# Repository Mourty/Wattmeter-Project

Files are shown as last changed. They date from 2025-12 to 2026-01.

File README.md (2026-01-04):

# The Wattmeter Project

This project was created for a senior design course as part of my degree path. I wanted to create a wattmeter similar to the "Kill A Watt" meters typically available, but with an important change. I wanted the ability to log the energy consumption data over time. I created a functional prototype well before I even began the class, but decided to iterate on the project and improve it. This is my first project of this scale, and I am sure it isn't perfect. In fact I'm sure it can be improved upon, but it works well enough for me.  
  
### Features
* Single Phase voltage, current, active power, reactive power, apparent power, frequency, and power factor measurement.
* LCD Display for user readable measurements.
* WiFi connectivity with RESTful API
* Configurable via SD card or web interface
* Dedicated Real time clock with automatic NTP syncing (WiFi required)
* Logs data to an SD card for optional independent operation
* Integrated UPS to prevent data loss due to power outage (100ish seconds plenty to automatically save data buffer)
* Monitoring server for remote data collection, storage, and presentation using React and python.

### Hardware
The hardware is a custom designed PCB with mostly through hole components. I chose through hole because it is what I wanted to use, more on this later.
The meter uses the Atmel M90E32 Poly-phase energy monitoring IC to do the heavy lifting of accurate power measurement. The voltage input uses a stepdown transformer and voltage divider to bring the 120VAC input voltage down around a manageable 0.6vrms. The transformer is somewhat unnecessary as a series of resistors could do the same, but this also provides some transient protection and isolation. The current measurement utilizes a current transformer with a carefully sizes burden resistor to bring the voltage down to around 0.6vrms when 20 amps is flowing though the primary of the CT. 
The power supply for the whole board is an off the shelf AC to DC power supply. This provides stable "safe" power without needed to roll my own PSU. This is fed to a super capacitor, then to the LM2621 based boost converted. The super capacitor provided an energy buffer to allow for controlled shutdown of the microcontroller in the event of a power outage. This allows time to write the current buffer of power statistics to the SD card. without this feature the SD card would either need to be written to more often with small amounts of data or the buffer would be lost during a power outage. Depending on the setting this could be multiple minutes or hours of data lost. The size of the super cap was chosen due to part availability at the time; It could easily be a quarter or even an eighth as large and still serve its purpose.
None of the components have been price optimized to a good degree. For example the diodes that are apart of the super capacitor/boost converter are rated for 2 amps, but don't ever see near that amount. These are simply what I had on hand during the design and didn't see a need to order different ones. So If you make this project too, you might want to consider components carefully, you might save some money.

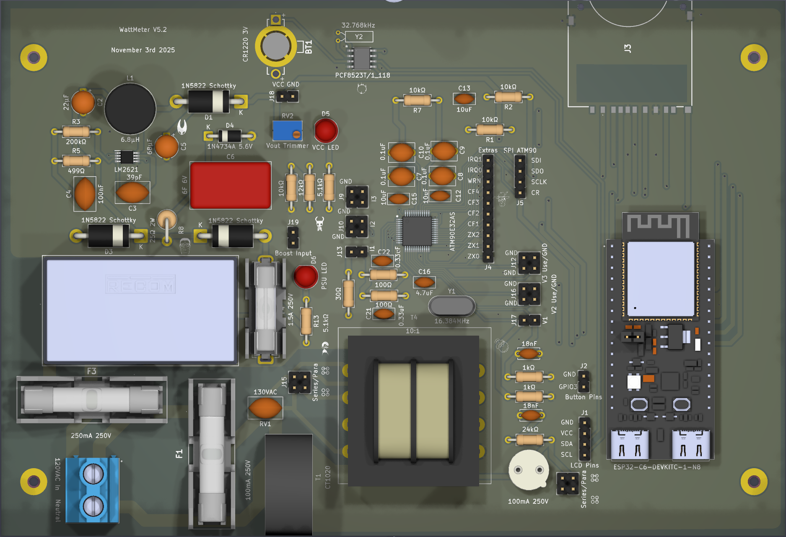
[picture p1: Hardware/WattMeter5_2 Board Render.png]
Wattmeter 5.2 Board Render.


I figured I could improve upon the wattmeter with the wattmeterJR. This version has fewer features, but is smaller and uses SMD components. It lacks an LCD display or the whole integrated UPS part. It is mainly to measure the same power statistics, but really requires the remote server to log the data. it is much less user friendly to build and to debug, but is cheaper and smaller. You can find this version at https://github.com/Mourty/WattmeterJR

### Firmware
I wrote the firmware with assistance from Claude.ai. I'm not the sort to go around proclaiming to be a coder, so you will find issues here. I used the Arduino IDE to develop, compile, and upload the code to the ESP32. The code is semi-organized into different files and imported where needed. The meter itself can be configured using the SD card. You will need to write the settings.ini to the SD card. In the settings you will find a place to configure your WiFi credentials as well as other settings. Many of these will seem cryptic, but most of them won't need to be modified at all. Most are actually configuration registers for the ATM90E32. You can find more on what the do in the IC's datasheet.  
  
### Service
The service is a web server that uses React for the front end and python for the backend. I again used Claude.ai to write much of the code here. The service is containerized using docker, so you should be able to get it up and running fairly easily. I used a Raspberry PI 3+, but in theory any linux computer can run this server. You will need to install docker to compose the containers and to run them. Docker *should* take care of installing other things for the containers like python and such.

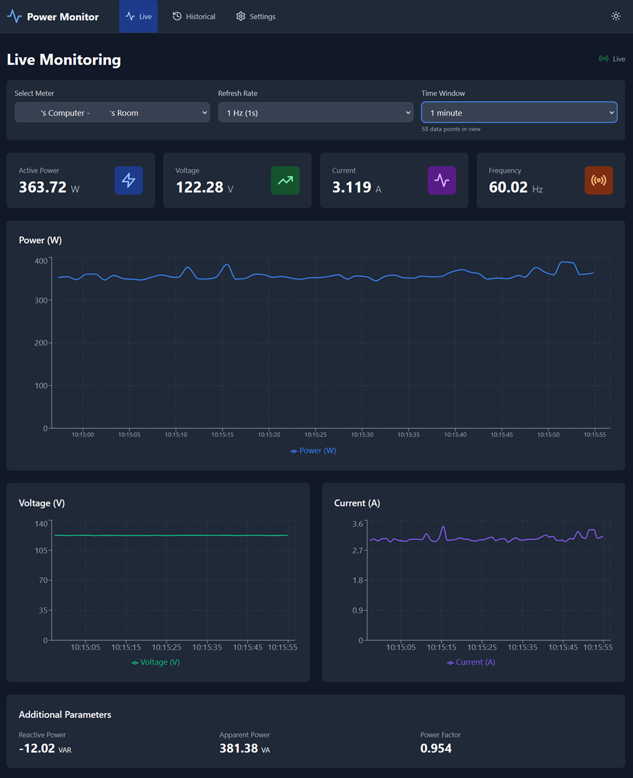
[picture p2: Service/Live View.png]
Live View.


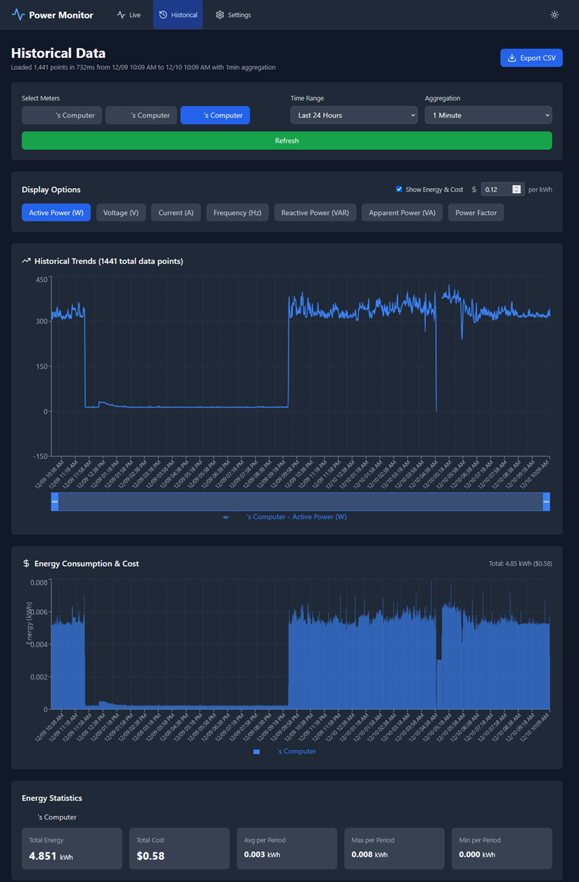
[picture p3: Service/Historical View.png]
Historical View.


I don't plan to maintain this or improve further at this time. If someone wants to improve this feel free, it won't hurt my feelings if you fork this project and do cool things with it, just give me credit for what you use. I have no idea what license this project should have given it uses a few external libraries, so before you go attempting to monetize this project you might need to check on that.

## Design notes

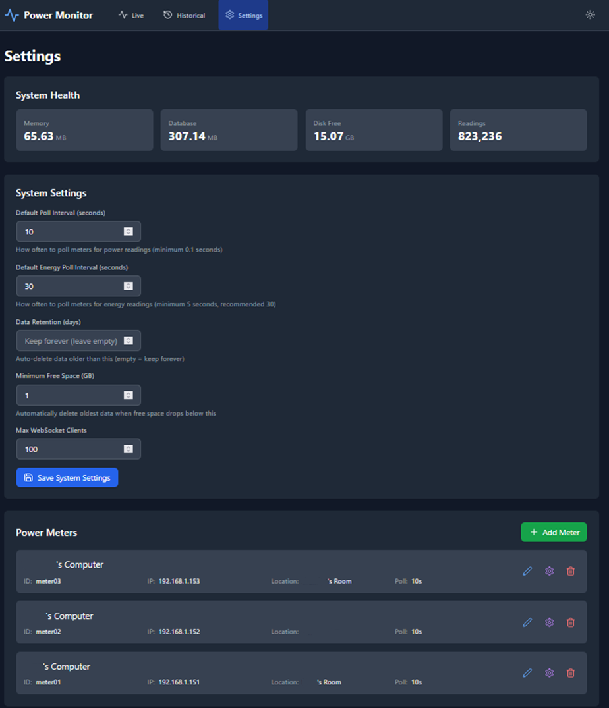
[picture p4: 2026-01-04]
Service/Settings View.png

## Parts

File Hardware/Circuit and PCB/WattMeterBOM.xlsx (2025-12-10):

Reference | Qty | Value | Mouser# | Digikey# | Amazon Link | Price/unit | Line Price
BT1 | 1 | CR1220 | 737-BH-127A-1 |  |  | 0.3 | 0.3
C12,C13,C15 | 3 | 10uF | 810-FG18X5R1E106MR00 |  |  | 0.278 | 0.834
C16 | 1 | 4.7uF | 810-FG28X5R1E475KRT6 |  |  | 0.22 | 0.22
C2 | 1 | 22μF | 581-TAP226K035CCS |  |  | 1.05 | 1.05
C21,C22 | 2 | 0.33uF | 810-FG18X7R1H334KRT6 |  |  | 0.115 | 0.23
C23,C24 | 2 | 18nF | 594-K183K10X7RF53H5 |  |  | 0.121 | 0.242
C3 | 1 | 39pF | 80-C317C390J2G |  |  | 0.12 | 0.12
C4 | 1 | 100nF | 594-K104K15X7RF53L2 |  |  | 0.106 | 0.106
C5 | 1 | 68μF | 581-TAP686K025CCS |  |  | 2.18 | 2.18
C6 | 1 | 6F 6V | 815-ADCMS06R0SA605RB |  |  | 5.51 | 5.51
C7,C8,C9,C10 | 4 | 0.1uF | 594-K104K15X7RF5WH5 |  |  | 0.089 | 0.356
D1,D2,D3 | 3 | 1N5822 Schottky | 511-1N5822 |  |  | 0.28 | 0.84
D4 | 1 | 1N4734A 5.6V | 78-1N4734A |  |  | 0.052 | 0.052
D5 | 1 | VCC LED | 859-LTL-4213 |  |  | 0.088 | 0.088
D6 | 1 | PSU LED | 859-LTL-4213 |  |  | 0.088 | 0.088
F1 | 1 | 100mA 250V | 576-0313.100MXP |  |  | 2.29 | 2.29
F2 | 1 | 100mA 250V | 693-0034.7105 |  |  | 0.814 | 0.814
F3 | 1 | 250mA 250V | 576-0313.250HXP |  |  | 1.43 | 1.43
F4 | 1 | 1.5A 250V |  |  | https://www.amazon.com/dp/B07MCHQQ7Z?ref=ppx_yo2ov_dt_b_fed_asin_title&th=1 | 1.67 | 1.67
IC1 | 1 | ATM90E32AS-AU-R | 556-ATM90E32AS-AU-R |  |  | 3.66 | 3.66
IC2 | 1 | LM2621MMX_NOPB | 926-LM2621MMX/NOPB |  |  | 1.77 | 1.77
J1 | 1 | LCD Pins | 910-HDR100IMP40MGVTH |  |  | 0.058 | 0.058
J10 | 1 | I2 Use/GND | 910-HDR100IMP40MGVTH |  |  | 0.058 | 0.058
J11 | 1 | Input | 490-TB005-762-02BE |  |  | 0.66 | 0.66
J12 | 1 | V3 Use/GND | 910-HDR100IMP40MGVTH |  |  | 0.058 | 0.058
J13 | 1 | I1 | 910-HDR100IMP40MGVTH |  |  | 0.029 | 0.029
J14,J15 | 2 | Series/Para | 910-HDR100IMP40MGVTH |  |  | 0.058 | 0.116
J16 | 1 | V2 Use/GND | 910-HDR100IMP40MGVTH |  |  | 0.058 | 0.058
J17 | 1 | V1 | 910-HDR100IMP40MGVTH |  |  | 0.029 | 0.029
J18 | 1 | VCC Pins | 910-HDR100IMP40MGVTH |  |  | 0.029 | 0.029
J19 | 1 | Boost Input | 910-HDR100IMP40MGVTH |  |  | 0.029 | 0.029
J2 | 1 | Button Pins | 910-HDR100IMP40MGVTH |  |  | 0.0145 | 0.0145
J3 | 1 | GSD09002SEU | 523-GSD09002SEU |  |  | 1.4 | 1.4
J4 | 1 | Extras | 910-HDR100IMP40MGVTH |  |  | 0.145 | 0.145
J5 | 1 | SPI ATM90 | 910-HDR100IMP40MGVTH |  |  | 0.058 | 0.058
J9 | 1 | I3 Use/GND | 910-HDR100IMP40MGVTH |  |  | 0.058 | 0.058
L1 | 1 | 6.8μH | 994-RFS1113-682ME |  |  | 1.65 | 1.65
N1 | 1 | Housing | 546-1591XXFBK |  |  | 19.07 | 19.07
P1 | 1 | Nema 5-15-P |  |  | https://www.amazon.com/Leviton-515PR-Straight-Blade-Rubber/dp/B000FKBZ7M | 3.98 | 3.98
P2 | 1 | Nema 5-15-R |  |  | https://www.amazon.com/dp/B0BMV8DSM1?ref=ppx_yo2ov_dt_b_fed_asin_title | 9.99 | 9.99
PS1 | 1 | RAC10E-05SK_277 | 919-RAC10E-05SK/277 |  |  | 9.64 | 9.64
R1,R2,R4,R7 | 4 | 10kΩ | 603-MFR-25FTE52-10K |  |  | 0.028 | 0.112
R10,R11 | 2 | 100Ω | MFR-25FBF52-100R |  |  | 0.029 | 0.058
R12,R13 | 2 | 5.1kΩ | 603-MFR-25FBF52-5K1 |  |  | 0.029 | 0.058
R14,R18 | 2 | 1kΩ | 603-MFR-25FBF52-1K |  |  | 0.026 | 0.052
R19 | 1 | 24kΩ | 603-MFR-25FBF52-24K |  |  | 0.029 | 0.029
R3 | 1 | 200kΩ | 603-MFR-25FBF52-200K |  |  | 0.029 | 0.029
R5 | 1 | 499Ω | 603-MFR-25FBF52-499R |  |  | 0.027 | 0.027
R6 | 1 | 12kΩ | 603-MFR-25FBF52-12K |  |  | 0.029 | 0.029
R8 | 1 | 25Ω 2W | 588-WNC25RFET |  |  | 1.46 | 1.46
R9 | 1 | 30Ω | 603-MFR-25FBF52-30R |  |  | 0.029 | 0.029
RV1 | 1 | 130VAC | 576-V07E130P |  |  | 0.186 | 0.186
RV2 | 1 | Vout Trimmer | 81-PV36W204C01B00 |  |  | 1.21 | 1.21
T1 | 1 | CT1020 |  | 419-CT1020-ND |  | 6.04 | 6.04
T4 | 1 | 10 to 1 | 838-3FD-224 |  |  | 4.5 | 4.5
U1 | 1 | ESP32-C6-DEVKITC-1-N8 | 356-ESP32C6DKC1N8 |  |  | 8.76 | 8.76
U2 | 1 | ~ |  |  | https://www.amazon.com/dp/B0C1G9GBRZ?ref=ppx_yo2ov_dt_b_fed_asin_title&th=1 | 5.66 | 5.66
U3 | 1 | PCF8523T/1_118 |  | 568-5306-1-ND |  | 1.29 | 1.29
Y1 | 1 | 16.384MHz | 815-ABL-16.384-B2 |  |  | 0.32 | 0.32
Y2 | 1 | 32.768kHz | 815-ABL-16.384-B2 |  |  | 0.32 | 0.32
Total |  |  |  |  |  |  | 101.1485

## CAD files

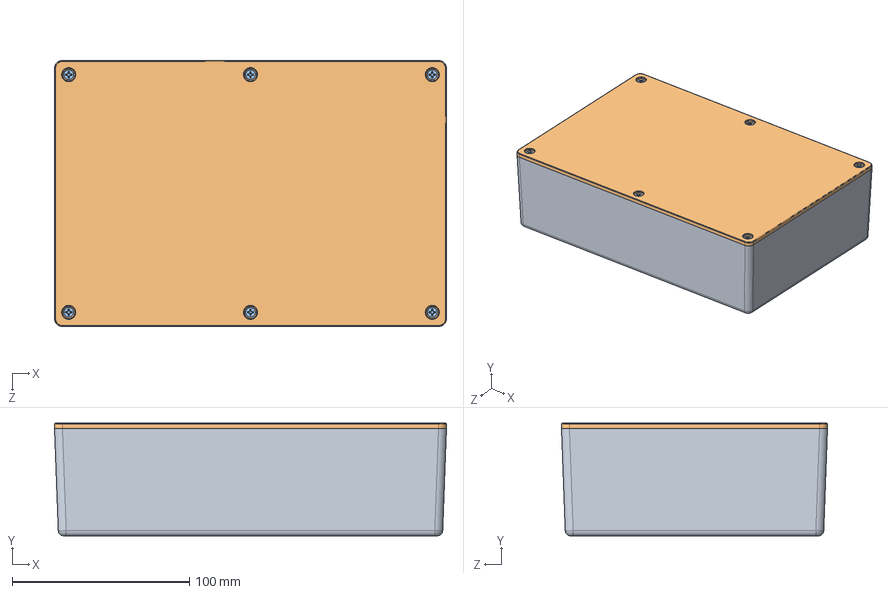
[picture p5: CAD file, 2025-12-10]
Hardware/Solidworks Parts/1591XXFBK.SLDASM
221.0 x 63.5 x 150.0 mm
1591XXF BOX.stp
1591XXF LID.stp
SC500 (screw M3-0.5X 10mm FH).stp x 6
IN100 (insert M3-0.5X5.75mm BRASS).stp x 6

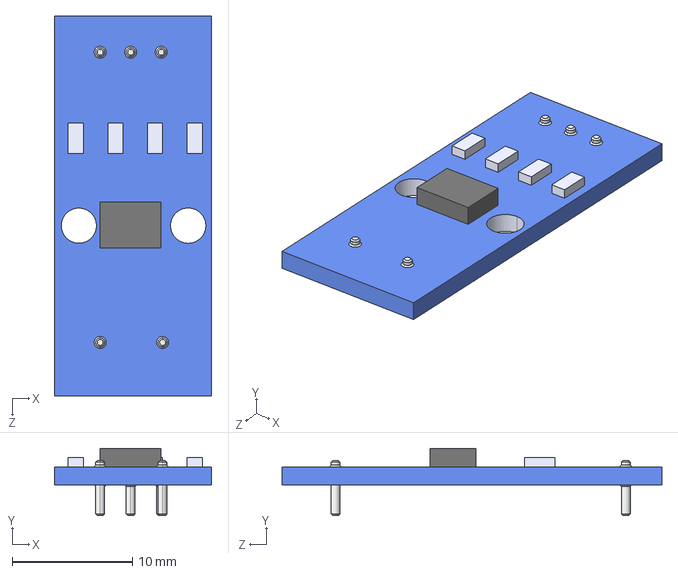
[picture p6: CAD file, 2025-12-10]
Hardware/Solidworks Parts/ACS712 Board.STEP
13.1 x 5.59 x 31.6 mm

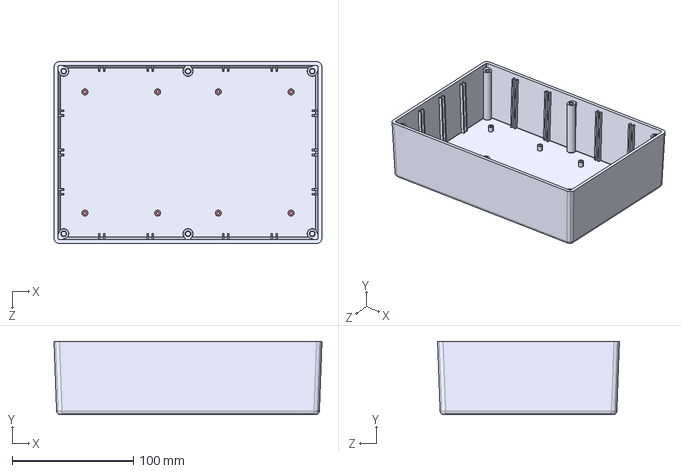
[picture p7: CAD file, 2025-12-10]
Hardware/Solidworks Parts/1591XXFBKBody.STEP
221.0 x 60.5 x 150.0 mm

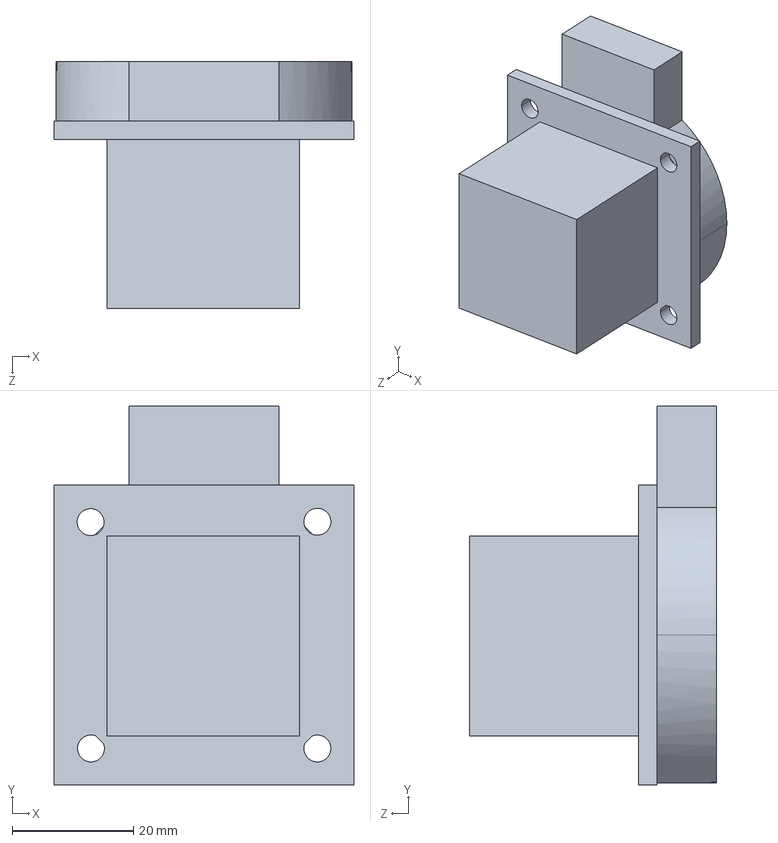
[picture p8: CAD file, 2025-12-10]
Hardware/Solidworks Parts/Nema5-15R Panel Mount.STEP
49.5 x 62.6 x 40.8 mm

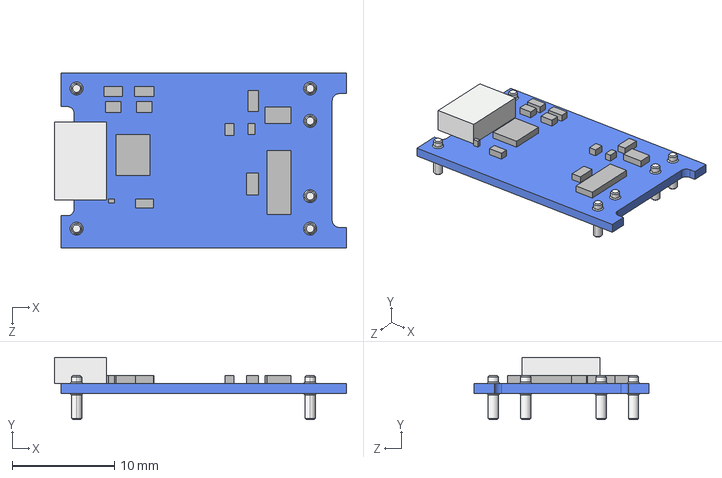
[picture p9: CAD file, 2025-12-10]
Hardware/Solidworks Parts/TP4056 Board.STEP
28.6 x 6.10 x 17.1 mm

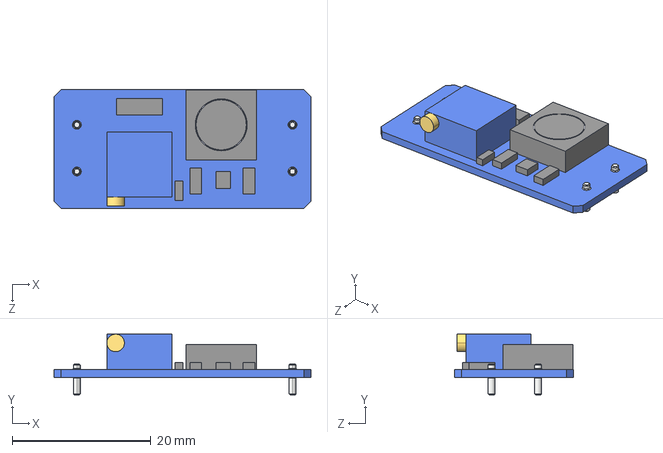
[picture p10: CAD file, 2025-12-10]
Hardware/Solidworks Parts/MT3608 board.STEP
37.1 x 8.76 x 17.1 mm

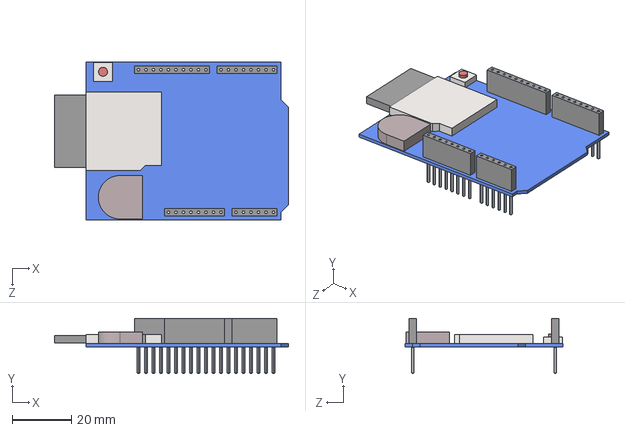
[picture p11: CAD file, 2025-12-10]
Hardware/Solidworks Parts/Datalogging Board.STEP
79.2 x 18.7 x 53.3 mm

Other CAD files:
Hardware/Solidworks Parts/ACS712 Board.SLDPRT
Hardware/Solidworks Parts/Datalogging Board.SLDPRT
Hardware/Solidworks Parts/MT3608 board.SLDPRT
Hardware/Solidworks Parts/Nema5-15R Panel Mount.SLDPRT
Hardware/Solidworks Parts/TP4056 Board.SLDPRT

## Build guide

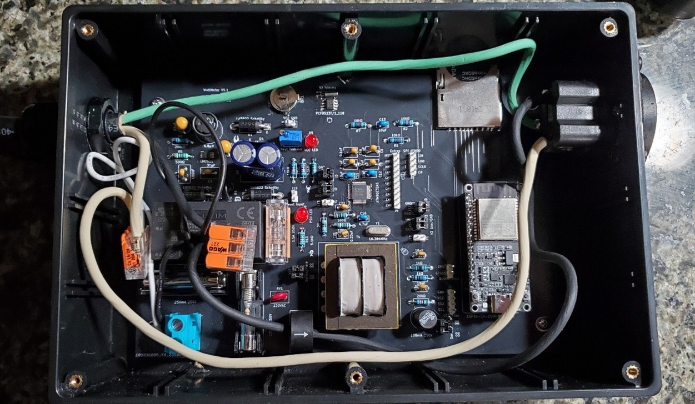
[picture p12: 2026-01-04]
Hardware/Assembled Meter Open Cover.jpg

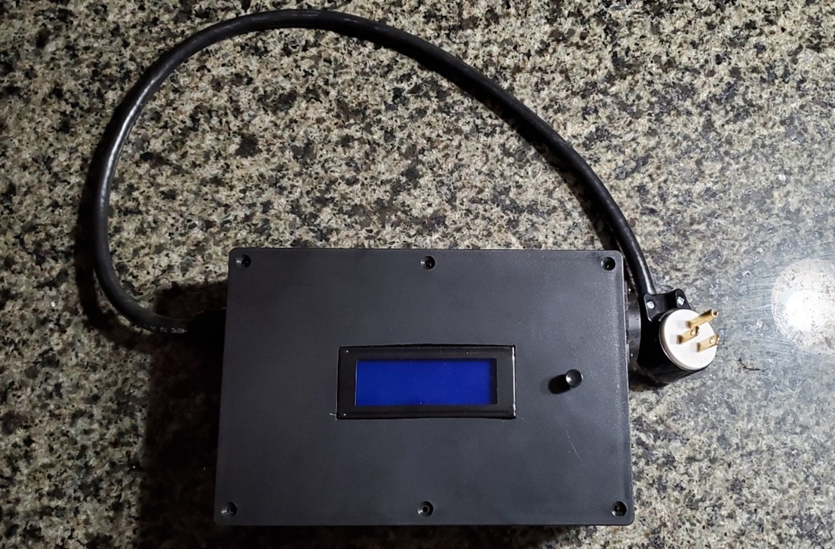
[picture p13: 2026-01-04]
Hardware/Assembled Meter.jpg

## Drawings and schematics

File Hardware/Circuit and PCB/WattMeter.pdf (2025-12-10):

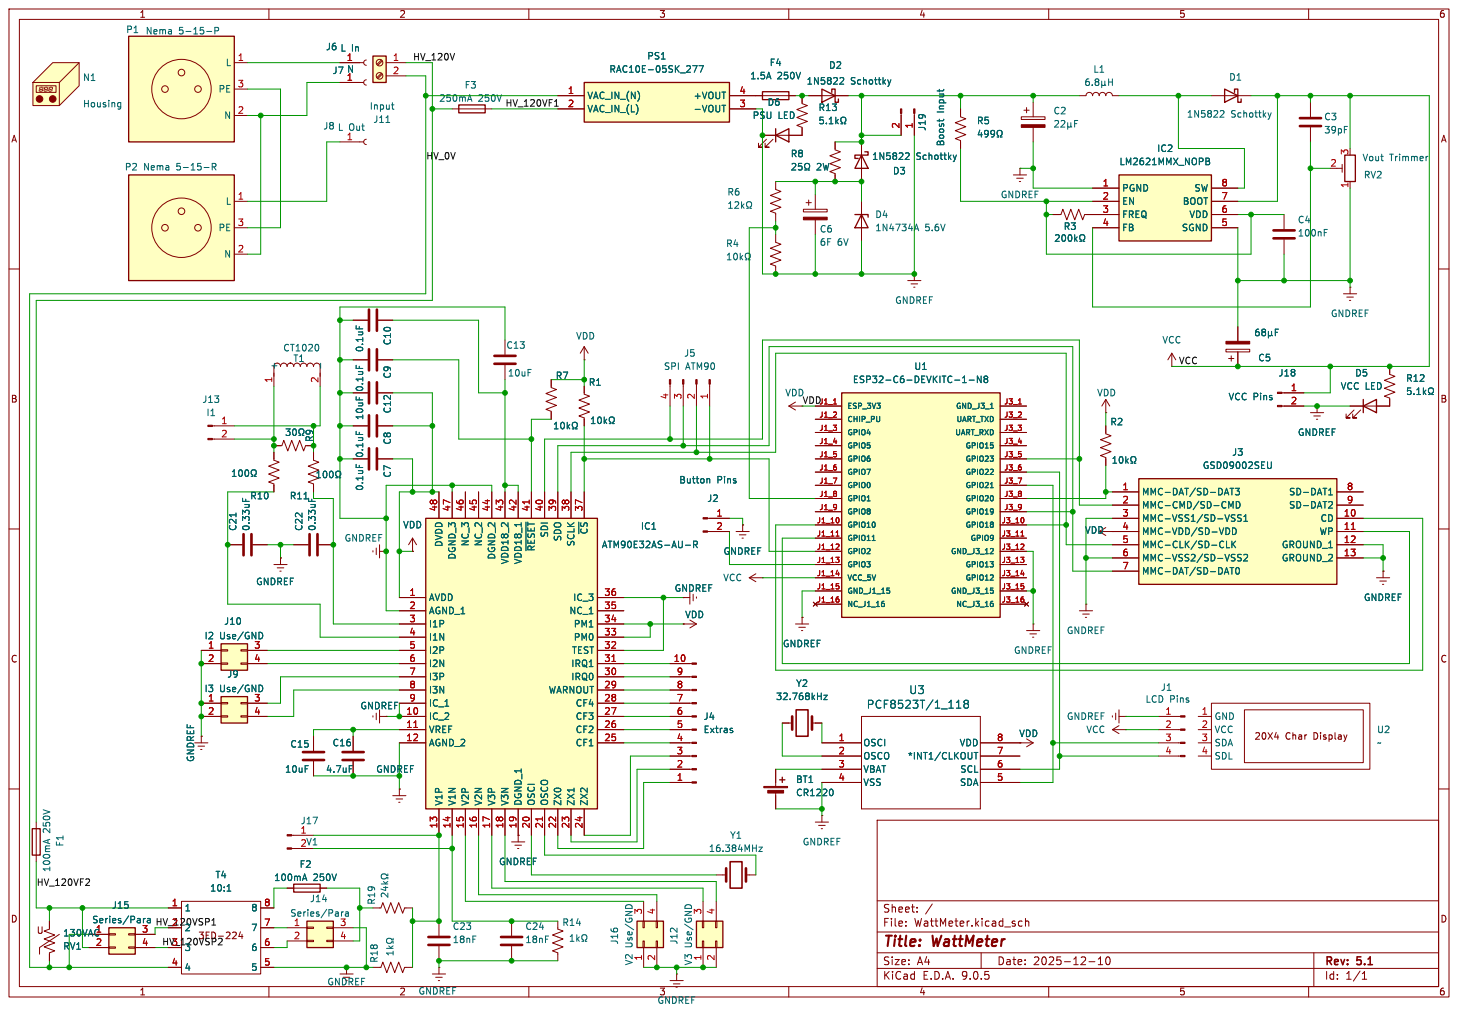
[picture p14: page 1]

4 J16 V2 Use/GND GNDREF GNDREF AVDD 1 AGND_1 2

Id: 1/1 Title: WattMeter File: WattMeter.kicad_sch Sheet: /

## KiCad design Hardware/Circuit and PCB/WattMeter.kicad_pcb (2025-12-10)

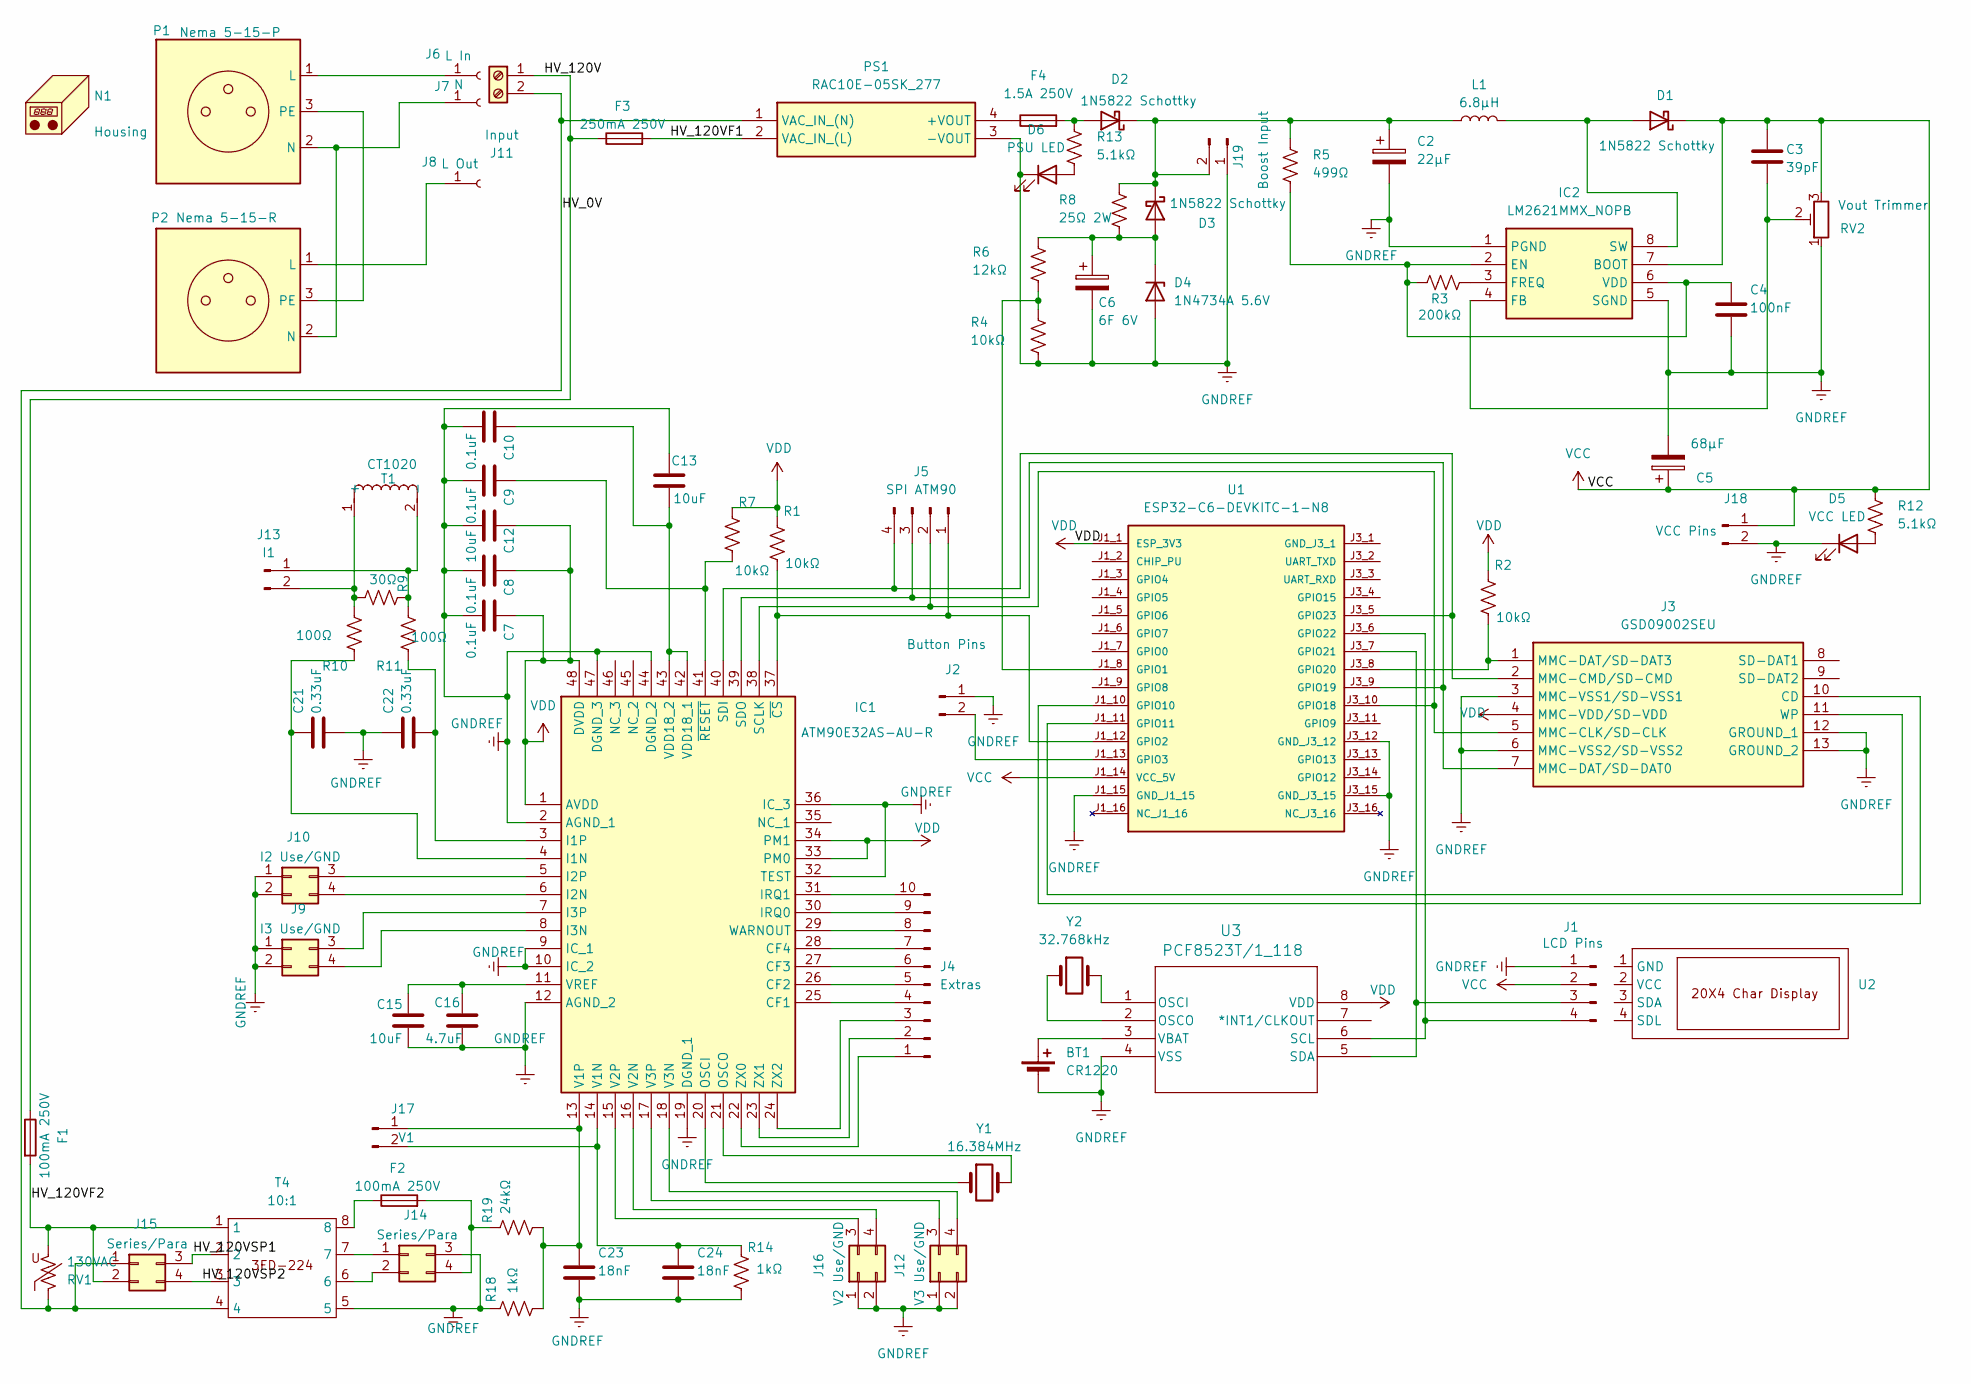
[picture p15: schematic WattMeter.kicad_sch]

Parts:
BT1: CR1220; BH127A1; Mouser# 737-BH-127A-1
C2: 22μF; CP_Radial_Tantal_D5.5mm_P5.00mm; Mouser# 581-TAP226K035CCS
C3: 39pF; C_Disc_D8.0mm_W5.0mm_P5.00mm; Mouser# 80-C317C390J2G
C4: 100nF; C_Disc_D8.0mm_W5.0mm_P5.00mm; Mouser# 594-K104K15X7RF53L2
C5: 68μF; CP_Radial_Tantal_D5.5mm_P5.00mm; Mouser# 581-TAP686K025CCS
C6: 6F 6V; C_Rect_L19.0mm_W11.0mm_P15.00mm_MKS4; Mouser# 815-ADCMS06R0SA605RB
C7, C8, C9, C10: 0.1uF; C_Disc_D6.0mm_W4.4mm_P5.00mm; Mouser# 594-K104K15X7RF5WH5
C12, C13, C15: 10uF; C_Disc_D5.0mm_W2.5mm_P2.50mm; Mouser# 810-FG18X5R1E106MR00
C16: 4.7uF; C_Disc_D5.0mm_W2.5mm_P2.50mm; Mouser# 810-FG28X5R1E475KRT6
C21, C22: 0.33uF; C_Disc_D5.0mm_W2.5mm_P2.50mm; Mouser# 810-FG18X7R1H334KRT6
C23, C24: 18nF; C_Disc_D5.0mm_W2.5mm_P5.00mm; Mouser# 594-K183K10X7RF53H5
D1, D2, D3: 1N5822 Schottky; D_DO-201AD_P15.24mm_Horizontal; Mouser# 511-1N5822
D4: 1N4734A 5.6V; D_DO-41_SOD81_P10.16mm_Horizontal; Mouser# 78-1N4734A
D5: VCC LED; LED_D5.0mm; Mouser# 859-LTL-4213
D6: PSU LED; LED_D5.0mm; Mouser# 859-LTL-4213
F1: 100mA 250V; 00318231; Mouser# 576-0313.100MXP
F2: 100mA 250V; Fuseholder_TR5_Littelfuse_No560_No460; Mouser# 693-0034.7105
F3: 250mA 250V; 00318231; Mouser# 576-0313.250HXP
F4: 1.5A 250V; Fuseholder_Clip-5x20mm_Keystone_3512P_Inline_P23.62x7.27mm_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
IC1: ATM90E32AS-AU-R; QFP50P900X900X120-48N; Mouser# 556-ATM90E32AS-AU-R
IC2: LM2621MMX_NOPB; SOP65P490X110-8N; Mouser# 926-LM2621MMX/NOPB
J1: LCD Pins; PinHeader_1x04_P2.54mm_Vertical; Mouser# 910-HDR100IMP40MGVTH
J2: Button Pins; PinHeader_1x02_P2.54mm_Vertical; Mouser# 910-HDR100IMP40MGVTH
J3: GSD09002SEU; Mouser# 523-GSD09002SEU
J4: Extras; PinHeader_1x10_P2.54mm_Vertical; Mouser# 910-HDR100IMP40MGVTH
J5: SPI ATM90; PinHeader_1x04_P2.54mm_Vertical; Mouser# 910-HDR100IMP40MGVTH
J6: L In
J7: N
J8: L Out
J9: I3 Use/GND; PinHeader_2x02_P2.54mm_Vertical; Mouser# 910-HDR100IMP40MGVTH
J10: I2 Use/GND; PinHeader_2x02_P2.54mm_Vertical; Mouser# 910-HDR100IMP40MGVTH
J11: Input; CUI_TB005-762-02BE; Mouser# 490-TB005-762-02BE
J12: V3 Use/GND; PinHeader_2x02_P2.54mm_Vertical; Mouser# 910-HDR100IMP40MGVTH
J13: I1; PinHeader_1x02_P2.54mm_Vertical; Mouser# 910-HDR100IMP40MGVTH
J14, J15: Series/Para; PinHeader_2x02_P2.54mm_Vertical; Mouser# 910-HDR100IMP40MGVTH
J16: V2 Use/GND; PinHeader_2x02_P2.54mm_Vertical; Mouser# 910-HDR100IMP40MGVTH
J17: V1; PinHeader_1x02_P2.54mm_Vertical; Mouser# 910-HDR100IMP40MGVTH
J18: VCC Pins; PinHeader_1x02_P2.54mm_Vertical; Mouser# 910-HDR100IMP40MGVTH
J19: Boost Input; PinHeader_1x02_P2.54mm_Vertical; Mouser# 910-HDR100IMP40MGVTH
L1: 6.8μH; L_Radial_D12.0mm_P5.00mm_Fastron_11P; Mouser# 994-RFS1113-682ME
N1: Housing; 1591XXF Enclosure 4 point; Mouser# 546-1591XXFBK
P1: Nema 5-15-P
P2: Nema 5-15-R
PS1: RAC10E-05SK_277; RAC10E05SK277; Mouser# 919-RAC10E-05SK/277
R1, R2, R4, R7: 10kΩ; R_Axial_DIN0207_L6.3mm_D2.5mm_P10.16mm_Horizontal; Mouser# 603-MFR-25FTE52-10K
R3: 200kΩ; R_Axial_DIN0207_L6.3mm_D2.5mm_P10.16mm_Horizontal; Mouser# 603-MFR-25FBF52-200K
R5: 499Ω; R_Axial_DIN0207_L6.3mm_D2.5mm_P10.16mm_Horizontal; Mouser# 603-MFR-25FBF52-499R
R6: 12kΩ; R_Axial_DIN0207_L6.3mm_D2.5mm_P10.16mm_Horizontal; Mouser# 603-MFR-25FBF52-12K
R8: 25Ω 2W; R_Axial_DIN0414_L11.9mm_D4.5mm_P5.08mm_Vertical; Mouser# 588-WNC25RFET
R9: 30Ω; R_Axial_DIN0207_L6.3mm_D2.5mm_P10.16mm_Horizontal; Mouser# 603-MFR-25FBF52-30R
R10, R11: 100Ω; R_Axial_DIN0207_L6.3mm_D2.5mm_P10.16mm_Horizontal; Mouser# MFR-25FBF52-100R
R12, R13: 5.1kΩ; R_Axial_DIN0207_L6.3mm_D2.5mm_P10.16mm_Horizontal; Mouser# 603-MFR-25FBF52-5K1
R14, R18: 1kΩ; R_Axial_DIN0207_L6.3mm_D2.5mm_P10.16mm_Horizontal; Mouser# 603-MFR-25FBF52-1K
R19: 24kΩ; R_Axial_DIN0207_L6.3mm_D2.5mm_P10.16mm_Horizontal; Mouser# 603-MFR-25FBF52-24K
RV1: 130VAC; C_Disc_D8.0mm_W5.0mm_P5.00mm; Mouser# 576-V07E130P
RV2: Vout Trimmer; Potentiometer_Bourns_3266Y_Vertical; Mouser# 81-PV36W204C01B00
T1: CT1020; Manufacturer_Part_Number CS1100L; Digikey# 419-CT1020-ND
T4: 10:1; 3FD-224; Mouser# 838-3FD-224
U1: ESP32-C6-DEVKITC-1-N8; MODULE_ESP32-C6-DEVKITC-1-N8; PARTREV 1.3; Mouser# 356-ESP32C6DKC1N8
U2: (no value)
U3: PCF8523T/1_118; SO8_SOT96-1_NXP; Digikey# 568-5306-1-ND
Y1: 16.384MHz; Crystal_HC49-U_Vertical; Mouser# 815-ABL-16.384-B2
Y2: 32.768kHz; Crystal_DS26_D2.0mm_L6.0mm_Horizontal; Mouser# 815-ABL-16.384-B2

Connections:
/HV_0V: J11.2, J15.1, PS1.1 (VAC_IN_(N)), RV1.1, T4.4
/HV_120V: F1.1, F3.1, J11.1
/HV_120VF1: F3.2, PS1.2 (VAC_IN_(L))
/HV_120VF2: F1.2, J15.2, RV1.2, T4.1
/HV_120VSP1: J15.3, T4.2
/HV_120VSP2: J15.4, T4.3
GNDREF: BT1.2 (-), C2.2, C4.2, C5.2, C6.2, C7.2, C8.2, C9.2, C10.2, C12.1, C13.2, C15.2, C16.2, C21.2, C22.1, C23.2, C24.2, D4.2 (A), D5.1 (K), D6.1 (K), IC1.2 (AGND_1), IC1.9 (IC_1), IC1.10 (IC_2), IC1.12 (AGND_2), IC1.19 (DGND_1), IC1.32 (TEST), IC1.36 (IC_3), IC1.44 (DGND_2), IC1.47 (DGND_3), IC2.1 (PGND), IC2.5 (SGND), J1.1, J2.1, J3.3 (MMC-VSS1/SD-VSS1), J3.6 (MMC-VSS2/SD-VSS2), J3.12 (GROUND_1), J3.13 (GROUND_2), J9.1, J9.2, J10.1, J10.2, J12.1, J12.2, J14.3, J16.1, J16.2, J18.2, J19.1, PS1.3 (-VOUT), R4.1, R14.1, R18.2, RV2.1, T4.5, U1.J1_15 (GND_J1_15), U1.J3_12 (GND_J3_12), U1.J3_15 (GND_J3_15), U3.4 (VSS)
unnamed: BT1.1 (+), U3.3 (VBAT)
unnamed: D1.2 (A), IC2.8 (SW), L1.2
unnamed: D2.2 (A), F4.2, R13.2
unnamed: C2.1, D2.1 (K), D3.1 (K), J19.2, L1.1, R5.2, R8.2
unnamed: C6.1, D3.2 (A), D4.1 (K), R6.2, R8.1
unnamed: D5.2 (A), R12.1
unnamed: D6.2 (A), R13.1
unnamed: F2.1, T4.8
unnamed: IC1.25 (CF1), J4.4
unnamed: IC1.26 (CF2), J4.5
unnamed: IC1.27 (CF3), J4.6
unnamed: IC1.28 (CF4), J4.7
unnamed: C21.1, IC1.4 (I1N), R10.2
unnamed: C22.2, IC1.3 (I1P), R11.2
unnamed: IC1.6 (I2N), J10.4
unnamed: IC1.5 (I2P), J10.3
unnamed: IC1.8 (I3N), J9.4
unnamed: IC1.7 (I3P), J9.3
unnamed: IC1.30 (IRQ0), J4.9
unnamed: IC1.31 (IRQ1), J4.10
unnamed: IC1.20 (OSCI), Y1.1
unnamed: IC1.21 (OSCO), Y1.2
unnamed: IC1.38 (SCLK), J3.5 (MMC-CLK/SD-CLK), J5.2, U1.J3_10 (GPIO18)
unnamed: IC1.40 (SDI), J3.2 (MMC-CMD/SD-CMD), J5.4, U1.J3_5 (GPIO23)
unnamed: IC1.39 (SDO), J3.7 (MMC-DAT/SD-DAT0), J5.3, U1.J3_9 (GPIO19)
unnamed: C24.1, IC1.14 (V1N), J17.2, R14.2
unnamed: C23.1, IC1.13 (V1P), J17.1, R18.1, R19.1
unnamed: IC1.16 (V2N), J16.4
unnamed: IC1.15 (V2P), J16.3
unnamed: IC1.18 (V3N), J12.4
unnamed: IC1.17 (V3P), J12.3
unnamed: C10.1, C13.1, IC1.42 (VDD18_1), IC1.43 (VDD18_2)
unnamed: C15.1, C16.1, IC1.11 (VREF)
unnamed: IC1.29 (WARNOUT), J4.8
unnamed: IC1.22 (ZX0), J4.1
unnamed: IC1.23 (ZX1), J4.2
unnamed: IC1.24 (ZX2), J4.3
unnamed: IC1.37 (~CS), J5.1, R1.1, U1.J1_12 (GPIO2)
unnamed: C9.1, IC1.41 (~RESET), R7.1
unnamed: C4.1, IC2.2 (EN), IC2.6 (VDD), R3.1, R5.1
unnamed: C3.2, IC2.4 (FB), RV2.2
unnamed: IC2.3 (FREQ), R3.2
unnamed: J1.3, U1.J3_7 (GPIO21), U3.5 (SDA)
unnamed: J1.4, U1.J3_6 (GPIO22), U3.6 (SCL)
unnamed: J2.2, U1.J1_13 (GPIO3)
unnamed: J3.10 (CD), U1.J1_10 (GPIO10)
unnamed: J3.1 (MMC-DAT/SD-DAT3), R2.1, U1.J3_8 (GPIO20)
unnamed: J3.11 (WP), U1.J1_11 (GPIO11)
unnamed: J6.1, P1.1 (L)
unnamed: J7.1, P1.2 (N), P2.2 (N)
unnamed: J8.1, P2.1 (L)
unnamed: J13.1, R9.2, R11.1, T1.2 (-)
unnamed: J13.2, R9.1, R10.1, T1.1 (+)
unnamed: J14.1, T4.7
unnamed: J14.2, T4.6
unnamed: F2.2, J14.4, R19.2
unnamed: P1.3 (PE), P2.3 (PE)
unnamed: F4.1, PS1.4 (+VOUT)
unnamed: R4.2, R6.1, U1.J1_8 (GPIO1)
unnamed: U3.1 (OSCI), Y2.2
unnamed: U3.2 (OSCO), Y2.1
VCC: C3.1, C5.1, D1.1 (K), IC2.7 (BOOT), J1.2, J18.1, R12.2, RV2.3, U1.J1_14 (VCC_5V)
VDD: C7.1, C8.1, C12.2, IC1.1 (AVDD), IC1.33 (PM0), IC1.34 (PM1), IC1.48 (DVDD), J3.4 (MMC-VDD/SD-VDD), R1.2, R2.2, R7.2, U1.J1_1 (ESP_3V3), U3.8 (VDD)

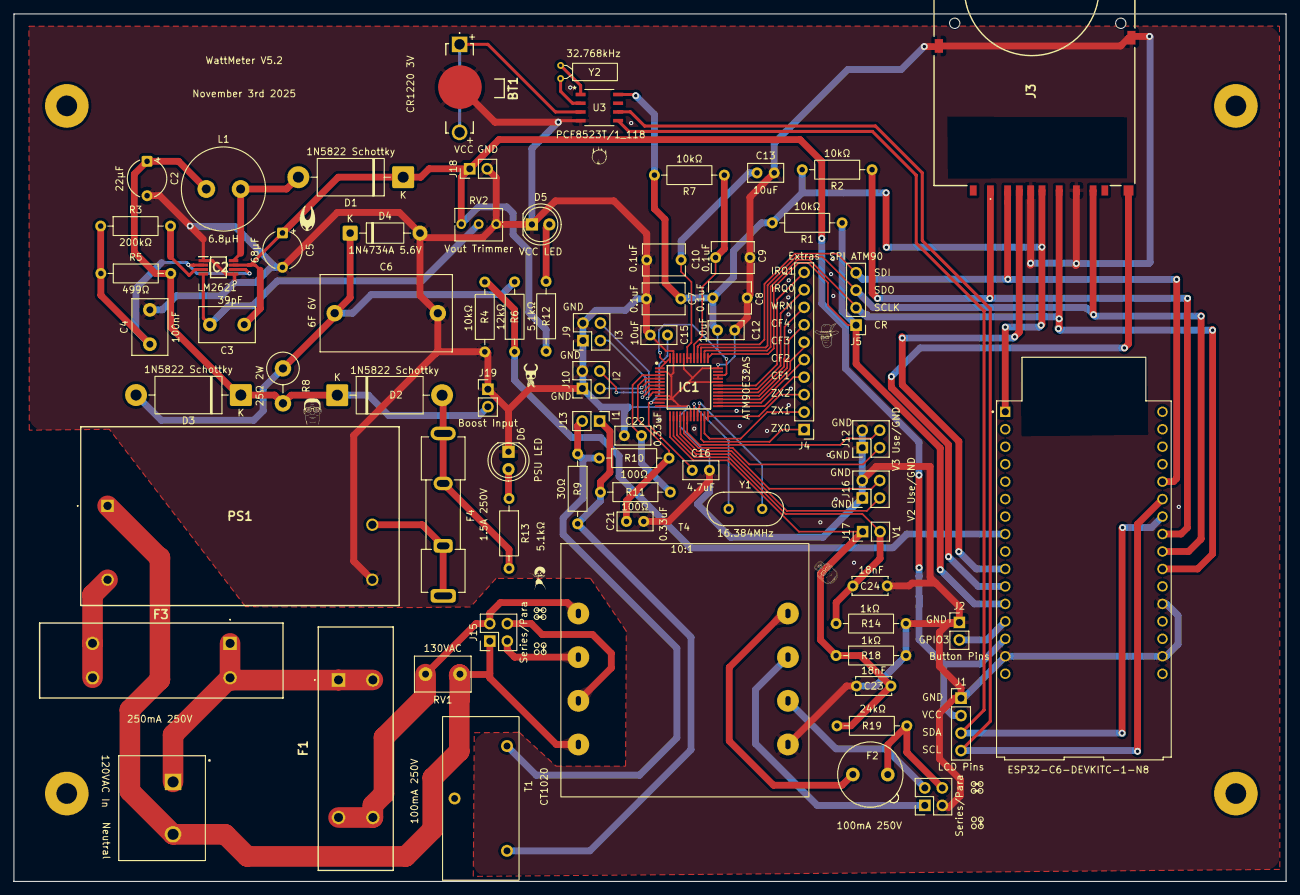
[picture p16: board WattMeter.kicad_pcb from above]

Board: 2 copper layers, 185.0 x 126.1 mm, 73 parts (0 on the bottom side), 66 nets.

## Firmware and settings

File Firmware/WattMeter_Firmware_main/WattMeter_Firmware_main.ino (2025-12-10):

#include <SPI.h>
#include <Wire.h>
#include <WiFi.h>
#include <Timezone.h>
#include <Time.h>
#include "ATM90E32.h"
#include "RegisterAccess.h"
#include "CommandParser.h"
#include "EnergyWebServer.h"
#include "SDCardLogger.h"
#include "SettingsManager.h"
#include "TimeManager.h"
#include "DisplayManager.h"
#include "RebootManager.h"
#include "EnergyAccumulator.h"



// Pin definitions
#define PIN_SPI_M90E32_CS 2  // Chip Select for M90ES32  (Active low)
#define SD_CS_PIN 20         // Chip Select for SD card  (Active Low)
#define SD_CD_PIN 10         // Card Detect
#define SD_WP_PIN 11         // Write Protect
#define PIN_SPI_SCLK 18      // Clock
#define PIN_SPI_MISO 19      // Master In Slave Out
#define PIN_SPI_MOSI 23      // Master Out Slave In
#define PIN_CAP_SENSE 1      // Super cap voltage sense pin
#define I2C_SDA 21           // I2C SDA pin
#define I2C_SDL 22           // I2C SDL pin
#define BUTTON_PIN 3


enum FaultCode {
  FAULT_NONE = 0,
  FAULT_SD_MISSING,
  FAULT_SD_SETTINGS_MISSING,
  FAULT_CHIP_INIT_FAILED,
  FAULT_RTC_INIT_FAILED
};

enum WarningCode {
  WARNING_NONE = 0,
  WARNING_SD_WRITE_PROTECTED
};



//Global Objects
LiquidCrystal_I2C lcd(0x27, 20, 4);
ATM90E32 energyChip(PIN_SPI_M90E32_CS);
RegisterAccess regAccess(energyChip);
TimeManager timeManager;
SDCardLogger sdLogger(regAccess, timeManager, SD_CS_PIN, SD_CD_PIN, SD_WP_PIN);
CommandParser cmdParser(regAccess);
EnergyWebServer EnergyWebServer(regAccess);
SettingsManager settings(regAccess);
EnergyAccumulator energyAccumulator(regAccess);
DisplayManager displayManager(regAccess, timeManager, sdLogger, EnergyWebServer, BUTTON_PIN);
RebootManager rebootManager(timeManager, sdLogger);



// Serial command buffer
String serialCommand = "";
//Heap check timer
static unsigned long lastHeapCheck = 0;

// ================ Settings Helpers ======================

// Apply WiFi settings to web server
bool applyWiFiSettings(const WiFiSettings& wifi) {
  if (wifi.ssid.length() == 0) {
    Serial.println("No WiFi SSID configured");
    return false;
  }

  Serial.println("\nConnecting to WiFi from settings...");
  if (EnergyWebServer.begin(wifi.ssid.c_str(), wifi.password.c_str())) {
    Serial.println("Connected to WiFi from saved settings");
    return true;
  } else {
    Serial.println("Failed to connect to WiFi");
    return false;
  }
}

// Apply RTC calibration settings and timezone
void applyRTCSettings(const RTCCalibrationSettings& rtc, const TimezoneSettings& tz) {
  Serial.println("Applying RTC calibration settings...");
  timeManager.setMinCalibrationDays(rtc.minCalibrationDays);
  timeManager.setCalibrationThreshold(rtc.calibrationThreshold);
  timeManager.setCalibrationEnabled(rtc.autoCalibrationEnabled);
  timeManager.setCalibrationData(rtc.lastCalibrationTime, rtc.currentOffset);

  if (rtc.currentOffset != 0) {
    timeManager.applyCalibrationOffset(rtc.currentOffset);
  }

  // Configure timezone
  char dstAbbrevBuffer[6];
  char stdAbbrevBuffer[6];

  // Copy the abbreviations into static storage
  strncpy(dstAbbrevBuffer, tz.dstAbbrev.c_str(), 5);
  dstAbbrevBuffer[5] = '\0';
  strncpy(stdAbbrevBuffer, tz.stdAbbrev.c_str(), 5);
  stdAbbrevBuffer[5] = '\0';


  TimeChangeRule dstRule = {
    "DST",
    tz.dstWeek,
    tz.dstDow,
    tz.dstMonth,
    tz.dstHour,
    tz.dstOffset
  };

  TimeChangeRule stdRule = {
    "STD",
    tz.stdWeek,
    tz.stdDow,
    tz.stdMonth,
    tz.stdHour,
    tz.stdOffset
  };

  timeManager.setTimezone(dstRule, stdRule);
}


// Sync RTC with NTP if needed
bool syncRTCIfNeeded(const RTCCalibrationSettings& rtc) {
  if (!timeManager.isRTCValid() || !timeManager.hasBeenSynced()) {
    Serial.println("\nSyncing RTC with NTP...");

    if (timeManager.syncFromNTP(rtc.ntpServer.c_str())) {
      RTCCalibrationSettings newSettings = rtc;
      time_t refTime;
      int8_t offset;
      timeManager.getCalibrationData(refTime, offset);
      newSettings.lastCalibrationTime = refTime;
      newSettings.currentOffset = offset;
      settings.setRTCCalibration(newSettings);
      timeManager.setAutoSyncInterval(86400);  // 24 hours
      settings.saveSettings();

      return true;
    }

    return false;
  } else {
    Serial.println("\nRTC already has valid time, skipping NTP sync");
    Serial.print("Current time: ");
    Serial.println(timeManager.getTimeString());

    // Set auto-sync for once per day
    timeManager.setAutoSyncInterval(86400);  // 24 hours
    return true;
  }
}

// Apply data logging settings
void applyDataLoggingSettings(const DataLoggingSettings& log) {
  Serial.println("Applying data logging settings...");

  // Set log fields FIRST (before allocating buffer)
  sdLogger.setLogFields(log.logFields);

  sdLogger.setBufferSize(log.bufferSize);
  sdLogger.setLoggingInterval(log.loggingInterval);
  sdLogger.setPowerLossThreshold(log.powerLossThreshold);
  sdLogger.enablePowerLossDetection(log.enablePowerLossDetection);
}

// Apply display settings
void applyDisplaySettings(const DisplaySettings& disp) {
  Serial.println("Applying display settings...");
  displayManager.setDisplayFields(disp.field0, disp.field1, disp.field2);
  displayManager.setBacklightTimeout(disp.backlightTimeout);
  displayManager.setLongPressTime(disp.longPressTime);
}

// Apply system settings
void applySystemSettings(const SystemSettings& sys) {
  Serial.println("Applying system settings...");
  rebootManager.enable(sys.autoRebootEnabled);
  rebootManager.setRebootInterval(sys.rebootIntervalHours);
  rebootManager.setRebootHour(sys.rebootHour);
}

// Apply all settings (for use after loading or reloading)
void applyAllSettings() {
  Serial.println("\n=== Applying All Settings ===");

  // Apply all registers to ATM90E32
  Serial.println("Applying all registers to ATM90E32...");
  settings.applyAllRegistersToChip();

  // Apply RTC settings AND timezone together
  applyRTCSettings(settings.getRTCCalibration(), settings.getTimezoneSettings());
  // Apply data logging settings
  applyDataLoggingSettings(settings.getDataLoggingSettings());
  // Apply display settings
  applyDisplaySettings(settings.getDisplaySettings());
  // Apply system settings
  applySystemSettings(settings.getSystemSettings());

  // Apply WiFi and sync time if possible
  if (applyWiFiSettings(settings.getWiFiSettings())) {
    syncRTCIfNeeded(settings.getRTCCalibration());

    // Enable logging if RTC is valid
    if (timeManager.isRTCValid()) {
      sdLogger.enableLogging(true);
    }
  }

  Serial.println("=== All Settings Applied ===\n");
}

void applyAllButWIFISettings() {
  Serial.println("\n=== Applying All Settings But WIFI ===");

  // Apply all registers to ATM90E32
  Serial.println("Applying all registers to ATM90E32...");
  settings.applyAllRegistersToChip();

  // Apply RTC settings AND timezone together
  applyRTCSettings(settings.getRTCCalibration(), settings.getTimezoneSettings());
  // Apply data logging settings
  applyDataLoggingSettings(settings.getDataLoggingSettings());
  // Apply display settings
  applyDisplaySettings(settings.getDisplaySettings());
  // Apply system settings
  applySystemSettings(settings.getSystemSettings());

  Serial.println("=== All Settings Applied But WIFI ===\n");
}


// ============== Fault and Warning System ==============





// Global warning state
struct {
  WarningCode activeWarning;
  unsigned long lastWarningDisplay;
  unsigned long warningDisplayInterval;
  unsigned long warningDisplayDuration;
  bool warningDisplayed;
} warningState = { WARNING_NONE, 0, 5000, 3000, false };

// Display a critical fault and halt system
void displayFault(FaultCode fault) {
  lcd.clear();
  lcd.backlight();
  lcd.setCursor(0, 0);
  lcd.print("*** FAULT ***");

  const char* line1 = nullptr;
  const char* line2 = nullptr;

  switch (fault) {
    case FAULT_SD_MISSING:
      line1 = "NO SD CARD FOUND";
      line2 = "Insert SD card";
      break;

    case FAULT_SD_SETTINGS_MISSING:
      line1 = "Settings file";
      line2 = "missing or invalid";
      break;

    case FAULT_CHIP_INIT_FAILED:
      line1 = "ATM90E32 chip";
      line2 = "init failed";
      break;

    case FAULT_RTC_INIT_FAILED:
      line1 = "RTC initialization";
      line2 = "failed";
      break;

    default:
      line1 = "Unknown fault";
      break;
  }

  if (line1) {
    lcd.setCursor(0, 1);
    lcd.print(line1);
  }

  if (line2) {
    lcd.setCursor(0, 2);
    lcd.print(line2);
  }

  // Log to serial
  Serial.println("\n=============================");
  Serial.println("*** CRITICAL FAULT ***");
  if (line1) Serial.println(line1);
  if (line2) Serial.println(line2);
  Serial.println("System will retry in 30 seconds...");
  Serial.println("=============================\n");

  // Display countdown and wait before retry
  for (int countdown = 30; countdown > 0; countdown--) {
    lcd.setCursor(0, 3);
    lcd.print("Retry in ");
    lcd.print(countdown);
    lcd.print(" sec   ");  // Extra spaces to clear previous longer numbers

    Serial.print("Retrying in ");
    Serial.print(countdown);
    Serial.println(" seconds...");

    delay(1000);
  }

  // Clear screen and show rebooting message
  lcd.clear();
  lcd.setCursor(0, 0);
  lcd.print("Rebooting...");
  Serial.println("Rebooting now...");
  delay(1000);

  // Restart the ESP32
  ESP.restart();
}

// Set an active warning (non-blocking)
void setWarning(WarningCode warning) {
  if (warningState.activeWarning != warning) {
    warningState.activeWarning = warning;
    warningState.warningDisplayed = false;
    warningState.lastWarningDisplay = 0;  // Display immediately
    Serial.print("WARNING: ");
    Serial.println(getWarningString(warning));
  }
}

// Clear active warning
void clearWarning() {
  if (warningState.activeWarning != WARNING_NONE) {
    Serial.println("Warning cleared");
    warningState.activeWarning = WARNING_NONE;
    warningState.warningDisplayed = false;
    // Force display update to restore normal view
    displayManager.forceUpdate();
  }
}

// Get warning string for serial output
const char* getWarningString(WarningCode warning) {
  switch (warning) {
    case WARNING_SD_WRITE_PROTECTED:
      return "SD card write protected";
    default:
      return "Unknown warning";
  }
}

// Display warning temporarily on LCD
void displayWarningOnLCD(WarningCode warning) {
  lcd.clear();
  lcd.backlight();
  lcd.setCursor(0, 0);
  lcd.print("!!! WARNING !!!");

  const char* line1 = nullptr;
  const char* line2 = nullptr;
  const char* line3 = nullptr;

  switch (warning) {
    case WARNING_SD_WRITE_PROTECTED:
      line1 = "SD card is";
      line2 = "write protected";
      line3 = "Logging disabled";
      break;

    default:
      line1 = "Unknown warning";
      break;
  }

  if (line1) {
    lcd.setCursor(0, 1);
    lcd.print(line1);
  }

  if (line2) {
    lcd.setCursor(0, 2);
    lcd.print(line2);
  }

  if (line3) {
    lcd.setCursor(0, 3);
    lcd.print(line3);
  }
}

// Update warning display system
void updateWarningDisplay() {
  unsigned long now = millis();

  // No active warning
  if (warningState.activeWarning == WARNING_NONE) {
    warningState.warningDisplayed = false;
    return;
  }

  // Check if it's time to display warning
  if (!warningState.warningDisplayed && (now - warningState.lastWarningDisplay >= warningState.warningDisplayInterval)) {

    // Display the warning
    displayWarningOnLCD(warningState.activeWarning);
    warningState.warningDisplayed = true;
    warningState.lastWarningDisplay = now;
  }

  // Check if it's time to restore normal display
  if (warningState.warningDisplayed && (now - warningState.lastWarningDisplay >= warningState.warningDisplayDuration)) {

    // Restore normal display
    displayManager.forceUpdate();
    warningState.warningDisplayed = false;
  }
}

// Configure warning display timing
void setWarningTiming(unsigned long displayInterval, unsigned long displayDuration) {
  warningState.warningDisplayInterval = displayInterval;
  warningState.warningDisplayDuration = displayDuration;
}


// ================ Setup ======================


void setup() {
  Wire.begin(I2C_SDA, I2C_SDL);

  Serial.begin(115200);

  Serial.println("\n\n=== ATM90E32 Energy Monitor ===");

  // Initialize LCD early so we can display errors
  lcd.init();
  lcd.backlight();
  lcd.setCursor(0, 0);
  lcd.print("Energy Monitor");
  lcd.setCursor(0, 1);
  lcd.print("Initializing...");

  // Initialize hardware
  SPI.begin(PIN_SPI_SCLK, PIN_SPI_MISO, PIN_SPI_MOSI);

  if (!energyChip.begin()) {
    Serial.println("ERROR: Failed to initialize ATM90E32");
    displayFault(FAULT_CHIP_INIT_FAILED);
  }
  Serial.println("ATM90E32 initialized");

  if (!timeManager.begin()) {
    Serial.println("ERROR: Failed to initialize RTC");
    displayFault(FAULT_RTC_INIT_FAILED);
  }

  // Critical: SD card must be present with settings
  if (!sdLogger.begin()) {
    Serial.println("ERROR: SD Card initialization failed");
    displayFault(FAULT_SD_MISSING);
  }

  // SD card is present, but can we load settings?
  if (!settings.loadSettings()) {
    Serial.println("ERROR: Failed to load settings from SD card");
    displayFault(FAULT_SD_SETTINGS_MISSING);
  }

  Serial.println("Settings loaded from SD card");

  // Continue with normal initialization
  displayManager.begin();

  // Apply all loaded settings
  applyAllSettings();

  // Link components to command parser
  cmdParser.setWebServer(&EnergyWebServer);
  cmdParser.setSDLogger(&sdLogger);
  cmdParser.setSettingsManager(&settings);
  cmdParser.setRebootManager(&rebootManager);

  //link settings manager to the webserver
  EnergyWebServer.setSettingsManager(&settings);

  // Initialize energy accumulator
  energyAccumulator.begin(&settings);
  EnergyWebServer.setEnergyAccumulator(&energyAccumulator);
  sdLogger.setEnergyAccumulator(&energyAccumulator);

  // Initialize reboot manager
  rebootManager.begin();

  // Configure warning display (5 seconds between, 3 seconds duration)
  setWarningTiming(5000, 3000);

  Serial.println("\n=== System Ready ===");
  Serial.print("Current time: ");
  Serial.println(timeManager.getTimeString());
  Serial.println("Type 'help' for available commands\n");
  cmdParser.printHelp();
  Serial.print("> ");
}

// ================ Main Loop ======================

void loop() {
  // Update warning display system
  updateWarningDisplay();

  // Handle web server requests
  EnergyWebServer.handleClient();

  // Update TimeManager (handles auto-sync with NTP)
  timeManager.update();

  // Handle SD card logging
  sdLogger.update();

  // Update energy accumulator (reads energy registers, saves periodically)
  energyAccumulator.update();

  // Update display (handles button, backlight, refresh)
  // Only update if no warning is currently being displayed
  if (!warningState.warningDisplayed) {
    displayManager.update();
  }


  // Check for warning condition(s)
  if (sdLogger.isCardPresent() && sdLogger.isWriteProtected()) {
    setWarning(WARNING_SD_WRITE_PROTECTED);
  } else {
    clearWarning();  // Clear if no warnings present
  }


  // Handle serial commands
  while (Serial.available() > 0) {
    char c = Serial.read();

    if (c == '\n' || c == '\r') {
      if (serialCommand.length() > 0) {
        cmdParser.parseCommand(serialCommand);
        serialCommand = "";
        Serial.print("\n> ");
      }
    } else {
      serialCommand += c;
    }
  }

  if (EnergyWebServer.settingsNeedReload()) {
    Serial.println("\n=== Reloading Settings After Remote Change ===");
    applyAllButWIFISettings();
  }

  if (sdLogger.settingsNeedReload()) {
    Serial.println("\n=== Reloading Settings After Power Restoration ===");

    if (settings.loadSettings()) {
      applyAllSettings();
      Serial.println("All settings reloaded and applied");
    } else {
      Serial.println("Failed to reload settings");
    }
  }


  if (millis() - lastHeapCheck >= 60000) {
    Serial.printf("Free heap: %u bytes\n", ESP.getFreeHeap());
    lastHeapCheck = millis();
  }

  // Small delay to prevent watchdog issues
  rebootManager.update();
  delay(1);
}

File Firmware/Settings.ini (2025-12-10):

[WiFi]
SSID=SomeWifiNameHere
Password=SuperGoodWIFIPassword

[RTCCalibration]
NTPServer=pool.ntp.org
MinCalibrationDays=1
CalibrationThreshold=5.0
AutoCalibrationEnabled=1
CalibrationEnabled=1
LastCalibrationTime=0
CurrentOffset=0

[Timezone]
; Daylight/Summer Time
DSTAbbrev=CDT
DSTWeek=2  ; 1=First, 2=Second, 3=Third, 4=Fourth, 5=Last
DSTDOW=1  ; 1=Sun, 2=Mon, 3=Tue, 4=Wed, 5=Thu, 6=Fri, 7=Sat
DSTMonth=3  ; 1-12
DSTHour=2  ; 0-23
DSTOffset=-300  ; Minutes from UTC (e.g., -300 for UTC-5)

; Standard Time
STDAbbrev=CST
STDWeek=1
STDDOW=1
STDMonth=11
STDHour=2
STDOffset=-360

[DataLogging]
LoggingInterval=1000
BufferSize=60
PowerLossThreshold=100.0
EnablePowerLossDetection=1
LogFields=UrmsA,IrmsA,PmeanA,QmeanA,SmeanA,Freq

[Display]
Field0=UrmsA
Field1=IrmsA
Field2=PmeanA
BacklightTimeout=30000
LongPressTime=10000

[System]
AutoRebootEnabled=1
RebootIntervalHours=168
RebootHour=9

[Energy_Accumulation]
EnergyReadInterval=20000  ; ms between energy register reads
EnergySaveInterval=600000  ; ms between saves to SD card
AccumulatedEnergyA=0.796860  ; kWh
AccumulatedEnergyB=0.000000  ; kWh
AccumulatedEnergyC=0.000000  ; kWh


[Status_and_Special_Registers]
IA_SRC=0x0	;ADC Input source for phase A current channel (Default: 0x0)
IB_SRC=0x1	;ADC Input source for phase B current channel (Default: 0x1)
IC_SRC=0x2	;ADC Input source for phase C current channel (Default: 0x2)
UA_SRC=0x4	;ADC Input source for phase A voltage channel (Default: 0x4)
UB_SRC=0x5	;ADC Input source for phase B voltage channel (Default: 0x5)
UC_SRC=0x6	;ADC Input source for phase C voltage channel (Default: 0x6)
Sag_Period=0x3F	;Voltage sag period (Default: 0x3F)
PeakDet_period=0x14	;Peak detect period (Default: 0x14)
OVth=0xC000              ; Over voltage threshold (Default: 0xC000)
Zxdis=0x1	;Zero-crossing Signal Disable (Default: 0x1)
ZX0Con=0x0	;ZX 0 Config (Default: 0x0)
ZX1Con=0x0	;ZX 1 Config (Default: 0x0)
ZX2Con=0x0	;ZX 2 Config (Default: 0x0)
ZX0Src=0x0	;ZX 0 Source (Default: 0x0)
ZX1Src=0x0	;ZX 1 Source (Default: 0x0)
ZX2Src=0x0	;ZX 2 Source (Default: 0x0)
SagTh=0x1000             ; Voltage sag threshold (Default: 0x1000)
PhaseLossTh=0x0400       ; Voltage phase loss threshold (Default: 0x0400)
InWarnTh=0xFFFF          ; Neutral current warning threshold (Default: 0xFFFF)
OIth=0xC000              ; Over current threshold (Default: 0xC000)
FreqLoTh=0x170C          ; Frequency low threshold (Default: 0x170C)
FreqHiTh=0x17D4          ; Frequency high threshold (Default: 0x17D4)
IRQ1_OR=0x0	;IRQ1 OR with IRQ0 (Default: 0)
WARN_OR=0x0	;WARN OR with IRQ0 (Default: 0)


[Configuration_Registers]
PL_Constant=0x0861C468          ;PL constant (Default: 0x0861C468)
EnPC=0x1	;Phase C all-Phase Sum energy enable (Default: 0x1)
EnPB=0x1	;Phase B all-Phase Sum energy enable (Default: 0x1)
EnPA=0x1	;Phase A all-Phase Sum energy enable (Default: 0x1)
ABSEnP=0x0	;Active Power summing method (Default: 0x0)
ABSEnQ=0x0	;Reactive Power summing method (Default: 0x0)
CF2varh=0x1	;CF2 Pin Source (Default: 0x1)
3P3W=0x0	;3 or 4 wire 3 phase mode	 (Default: 0x0)
didtEn=0x0	;Enable Integrator for didt current sensor (Default: 0x0)
HPFoff=0x0	;Disable HPF Signal processing (Default: 0x0)
Freq60Hz=0x1	;Grid frequency flag (Default: 0x1)
PGA_GAIN=0x0000	;PGA Gain Config (Default 0x0000)
PStartTh=0x0000          ; Active startup power threshold (Default: 0x0000)
QStartTh=0x0000          ; Reactive startup power threshold (Default: 0x0000)
SStartTh=0x0000          ; Apparent startup power threshold (Default: 0x0000)
PPhaseTh=0x0000          ; Phase active power startup threshold (Default: 0x0000)
QPhaseTh=0x0000          ; Phase reactive power startup threshold (Default: 0x0000)
SPhaseTh=0x0000          ; Phase apparent power startup threshold (Default: 0x0000)

[Calibration_Registers]
PoffsetA=0x0000          ; Phase A active power offset (Default: 0x0000)
QoffsetA=0x0000          ; Phase A reactive power offset (Default: 0x0000)
PoffsetB=0x0000          ; Phase B active power offset (Default: 0x0000)
QoffsetB=0x0000          ; Phase B reactive power offset (Default: 0x0000)
PoffsetC=0x0000          ; Phase C active power offset (Default: 0x0000)
QoffsetC=0x0000          ; Phase C reactive power offset (Default: 0x0000)
PQGainA=0xFF8E           ; Phase A energy calibration gain (Default: 0x0000)
PhiA=0x0000              ; Phase A energy calibration phase angle (Default: 0x0000)
PQGainB=0x0000           ; Phase B energy calibration gain (Default: 0x0000)
PhiB=0x0000              ; Phase B energy calibration phase angle (Default: 0x0000)
PQGainC=0x0000           ; Phase C energy calibration gain (Default: 0x0000)
PhiC=0x0000              ; Phase C energy calibration phase angle (Default: 0x0000)
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

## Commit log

2025-12-10 Add some plots
    [WattMeter.csv, WattMeter.kicad_pcb, WattMeter.kicad_sch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]
2026-01-04 Add Board Render
